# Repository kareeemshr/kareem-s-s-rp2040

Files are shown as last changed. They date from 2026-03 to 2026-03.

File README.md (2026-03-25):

# kareem-s-s-rp2040
(small note:there are decoupiling cap's clumped up together cus of space restrictions and no i cant really make the pcb 4 layers because im like 10 bucks away from being over budget)my very own custom devboard that i made...well i made it cus i thought itd be cool as hell and it is,im very proud of myself for making it but nonetheless:

you can use it like a normal raspberry pi pico as far as im aware.

i made it just to learn to how do this type of stuff because i really love the idea of me making my own stuff instead of buying it premade for me so like you could say my dream rn is to build my own custom keyboard but thats for when im actually good at this stuff and also when i get enough money.

**heres the schematic:**

**heres the pcb:**


**heres a render of the board(dont mind the drawings im inlove with sparta and the BOS)**:

|part|ammount|value|link|foot print|
|:----|:---:|:----:|----|----|
|Capacitor|11|0.1uF|https://jlcpcb.com/partdetail/1877-CL05B104KO5NNNC/C1525|0402|
|Capacitor|2|1uF|https://jlcpcb.com/partdetail/53938-CL05A105KA5NQNC/C52923|0402|
|capacitor|2|10uF|https://jlcpcb.com/partdetail/20411-CL10A106KP8NNNC/C19702|0603|
|capacitor|2|33pF|https://jlcpcb.com/partdetail/1914-0402CG330J500NT/C1562|0402|
|resistor|2|5.1K|https://jlcpcb.com/partdetail/26648-0402WGF5101TCE/C25905|0402|
|resistor|2|27|https://jlcpcb.com/partdetail/25843-0402WGF270JTCE/C25100|0402|
|resistor|2|1K|https://jlcpcb.com/partdetail/12256-0402WGF1001TCE/C11702|0402|
|resistor|1|10K|https://jlcpcb.com/partdetail/26487-0402WGF1002TCE/C25744|0402|
|push button|1||https://jlcpcb.com/partdetail/XUNPU-TS_1088AR02016/C720477|SW_Push_SPST_NO_Alps_SKRK|
|usb-c input|1||https://jlcpcb.com/partdetail/Korean_HropartsElec-TYPE_C_31_M12/C165948|USB_C_Receptacle_HRO_TYPE-C-31-M-12|
|MCU(rp 2040)|1||https://jlcpcb.com/partdetail/RaspberryPi-RP2040/C2040|QFN-56-1EP_7x7mm_P0.4mm_EP3.2x3.2mm|
|flash mem(W25Q16JVSS)|1|16MB|https://jlcpcb.com/partdetail/WinbondElec-W25Q16JVSSIQ/C131025|SOIC-8_5.3x5.3mm_P1.27mm|
|LOD(MCP1700x-330xxTT)|1|5.5V inpt 3.3V outp|https://jlcpcb.com/partdetail/MSKSEMI-MCP1700T_3302E_TT_MS/C20627188|SOT-23|
|crystal|1|12MHZ|https://jlcpcb.com/partdetail/NDK-NX3225GA_12MHZ_STD_CRG2/C481407|Crystal_SMD_3225-4Pin_3.2x2.5mm|

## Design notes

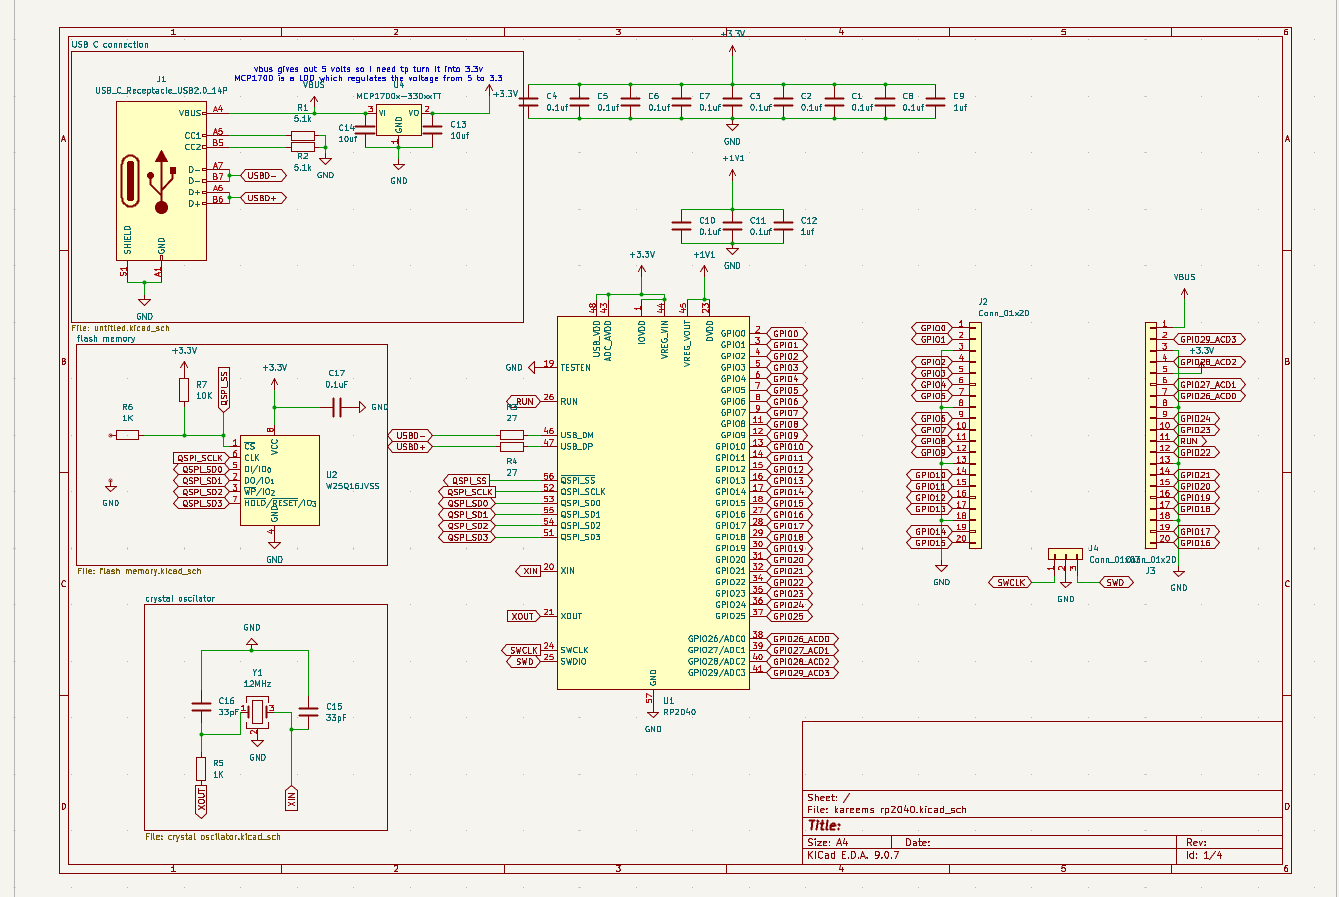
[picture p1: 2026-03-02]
photos/Screenshot 2026-03-03 020434.png

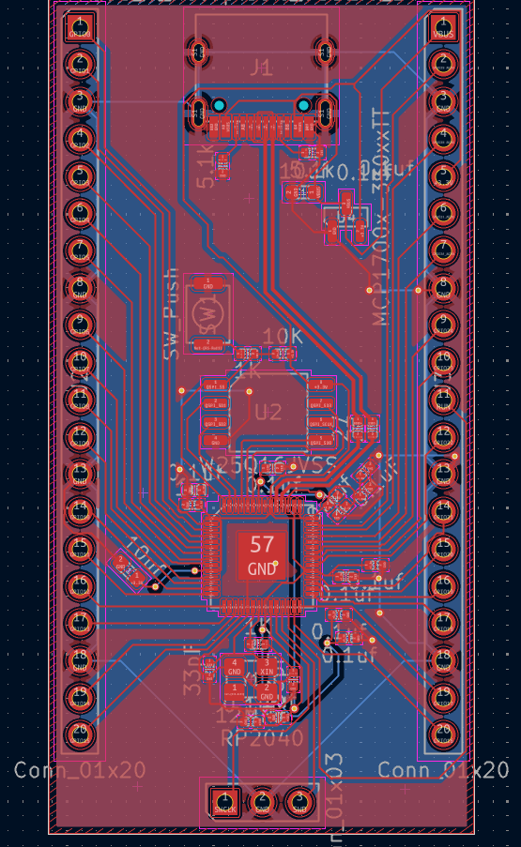
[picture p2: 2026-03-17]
photos/Screenshot 2026-03-17 214747.png

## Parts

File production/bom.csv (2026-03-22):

Designator | Footprint | Quantity | Value | LCSC Part #
C1, C10, C11, C17, C2, C3, C4, C5, C6, C7, C8 | 0402 | 11 | 0.1uf
C12, C9 | 0402 | 2 | 1uf
C13, C14 | 0603 | 2 | 10uf
C15, C16 | 0402 | 2 | 33pF
J1 | USB_C_Receptacle_HRO_TYPE-C-31-M-12 | 1 | USB_C_Receptacle_USB2.0_14P
J2, J3 | PinHeader_1x20_P2.54mm_Vertical | 2 | Conn_01x20
J4 | PinHeader_1x03_P2.54mm_Vertical | 1 | Conn_01x03
R1, R2 | 0402 | 2 | 5.1k
R3-1, R4+1 | 0402 | 2 | 27
R5, R6 | 0402 | 2 | 1K
R7 | 0402 | 1 | 10K
SW1 | SW_Push_SPST_NO_Alps_SKRK | 1 | SW_Push
U1 | QFN-56-1EP_7x7mm_P0.4mm_EP3.2x3.2mm | 1 | RP2040
U2 | SOIC-8_5.3x5.3mm_P1.27mm | 1 | W25Q16JVSS
U4 | SOT-23 | 1 | MCP1700x-330xxTT
Y1 | Crystal_SMD_3225-4Pin_3.2x2.5mm | 1 | 12MHz

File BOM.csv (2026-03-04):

part | value | ammount | link
C1 C10 C11 C17 C2 C3 C4 C5 C6 C7 C8 | 0.1uf | 11 | https://jlcpcb.com/partdetail/1877-CL05B104KO5NNNC/C1525
C12 C9 | 1uf | 2 | https://jlcpcb.com/partdetail/53938-CL05A105KA5NQNC/C52923
C13 C14 | 10uf | 2 | https://jlcpcb.com/partdetail/20411-CL10A106KP8NNNC/C19702
C15 C16 | 33pF | 2 | https://jlcpcb.com/partdetail/1914-0402CG330J500NT/C1562
USB_C_Receptacle_USB2.0_14P |  | 1 | https://jlcpcb.com/partdetail/Korean_HropartsElec-TYPE_C_31_M12/C165948
R1 R2 | 5.1K | 2 | https://jlcpcb.com/partdetail/26648-0402WGF5101TCE/C25905
R3 R4 | 27 | 2 | https://jlcpcb.com/partdetail/25843-0402WGF270JTCE/C25100
R5 R6 | 1K | 2 | https://jlcpcb.com/partdetail/12256-0402WGF1001TCE/C11702
R7 | 10K | 1 | https://jlcpcb.com/partdetail/26487-0402WGF1002TCE/C25744
SW1 |  | 1 | https://jlcpcb.com/partdetail/XUNPU-TS_1088AR02016/C720477
RP2040 |  | 1 | https://jlcpcb.com/partdetail/RaspberryPi-RP2040/C2040
W25Q16JVSS |  | 1 | https://jlcpcb.com/partdetail/WinbondElec-W25Q16JVSSIQ/C131025
MCP1700x-330xxTT |  | 1 | https://jlcpcb.com/partdetail/MSKSEMI-MCP1700T_3302E_TT_MS/C20627188
crystal | 12MHZ | 1 | https://jlcpcb.com/partdetail/NDK-NX3225GA_12MHZ_STD_CRG2/C481407

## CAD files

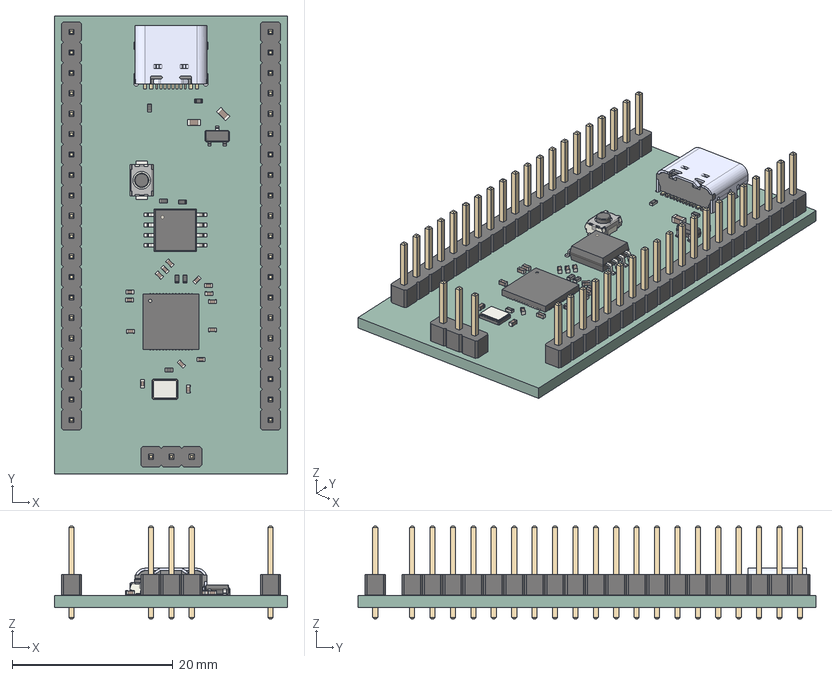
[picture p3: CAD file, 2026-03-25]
kareems rp2040.step
29.0 x 57.0 x 11.5 mm
R_0402_1005Metric x 7
C_0402_1005Metric x 15
SOIC-8_5.3x5.3mm_P1.27mm
QFN-56-1EP_7x7mm_P0.4mm_EP3.2x3.2mm
C_0603_1608Metric x 2
TYPE-C-31-M-12
Crystal_SMD_3225-4Pin_3.2x2.5mm
PinHeader_1x03_P2.54mm_Vertical
PinHeader_1x20_P2.54mm_Vertical x 2
SOT-23
SW_Push_SPST_NO_Alps_SKRK
kareems rp2040_PCB

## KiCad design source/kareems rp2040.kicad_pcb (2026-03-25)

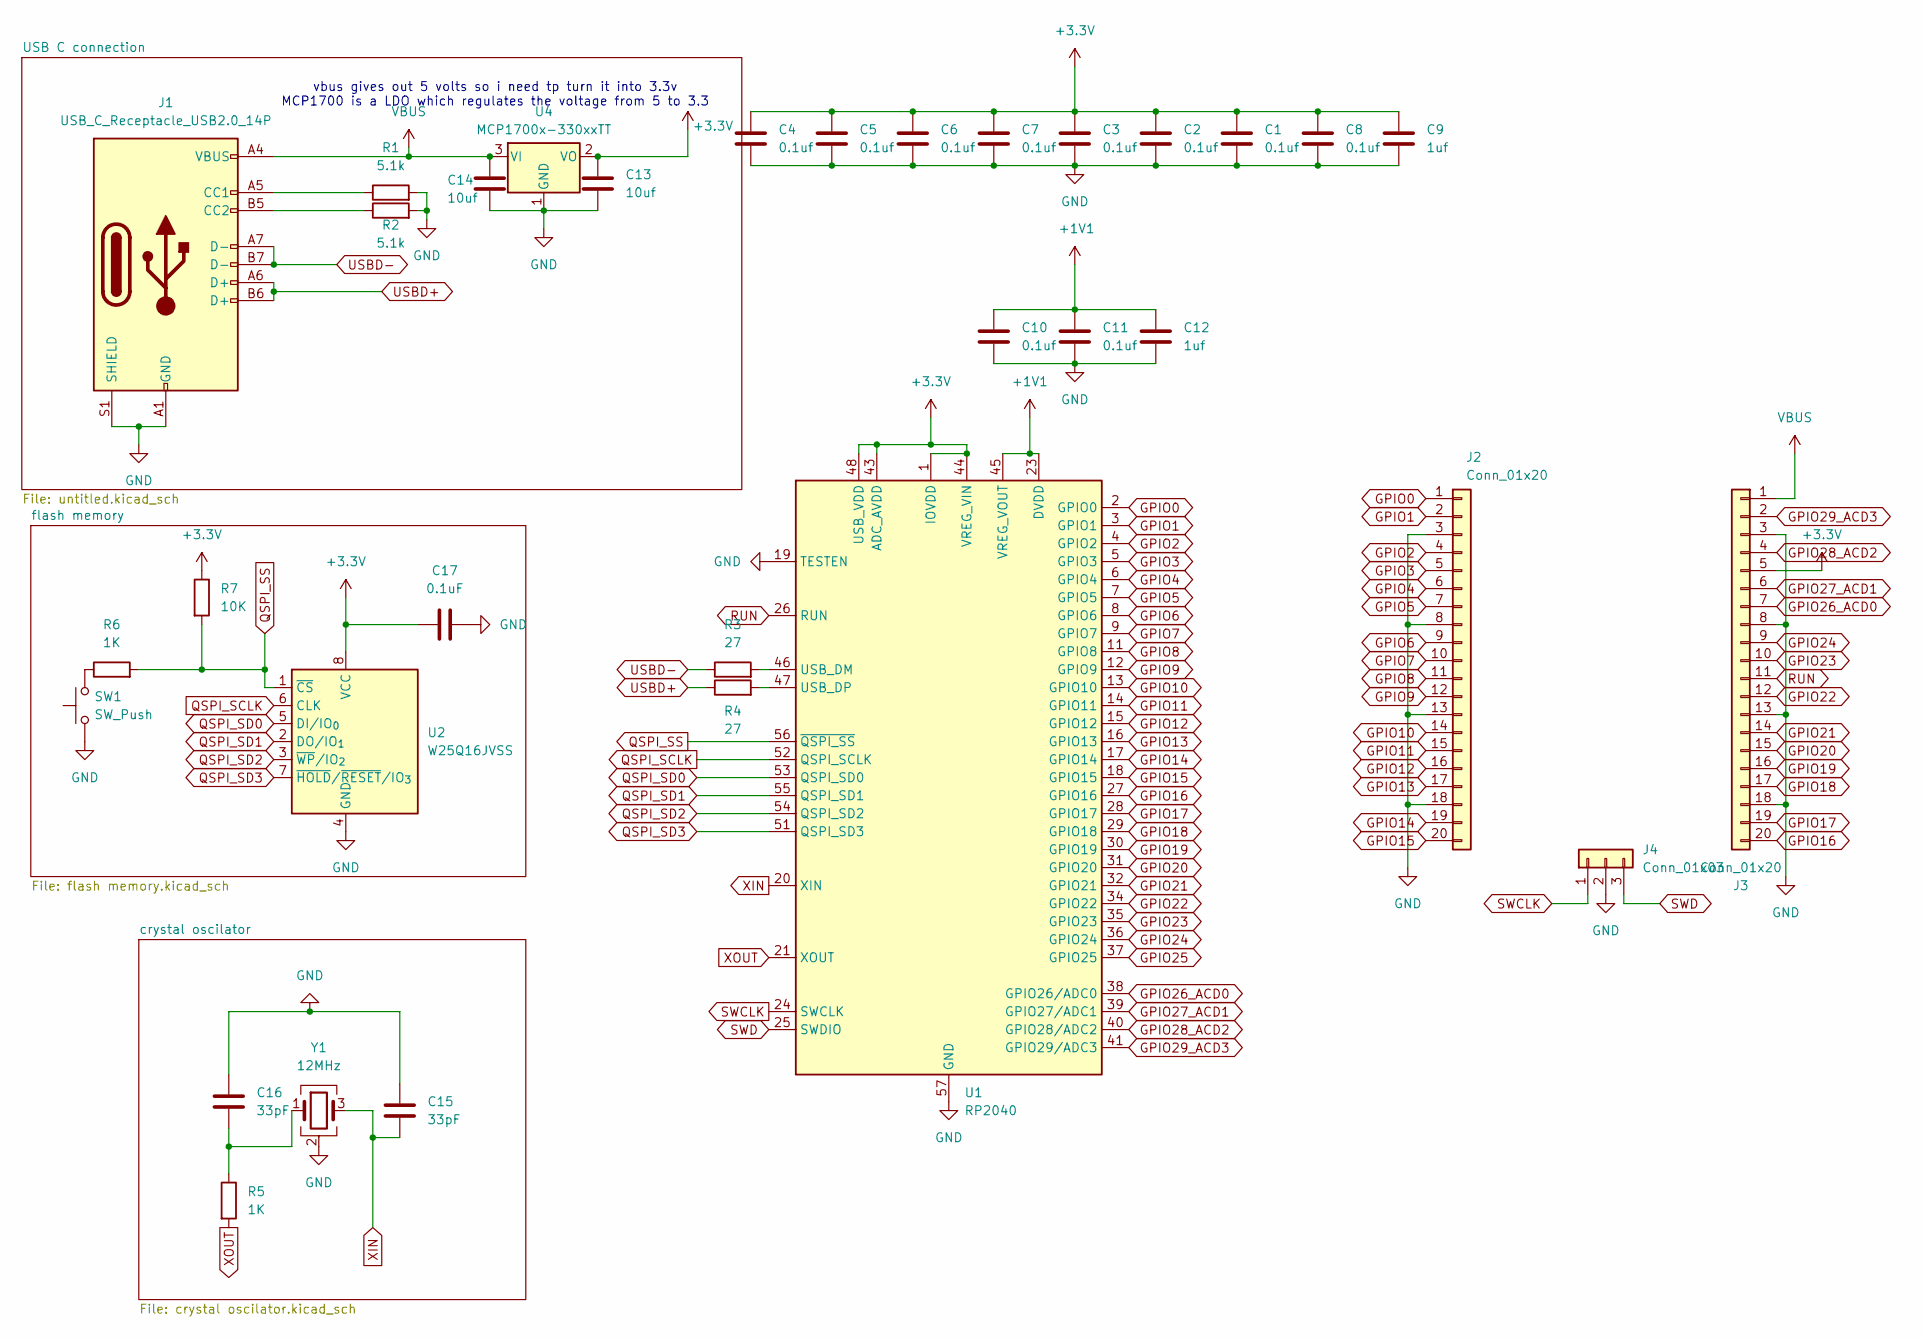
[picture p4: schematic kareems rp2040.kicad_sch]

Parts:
C1, C2, C3, C4, C5, C6, C7, C8, C10, C11: 0.1uf; C_0402_1005Metric
C9, C12: 1uf; C_0402_1005Metric
C13, C14: 10uf; C_0603_1608Metric
C15, C16: 33pF; C_0402_1005Metric
C17: 0.1uF; C_0402_1005Metric
J1: USB_C_Receptacle_USB2.0_14P; USB_C_Receptacle_HRO_TYPE-C-31-M-12
J2, J3: Conn_01x20; PinHeader_1x20_P2.54mm_Vertical
J4: Conn_01x03; PinHeader_1x03_P2.54mm_Vertical
R1, R2: 5.1k; R_0402_1005Metric
R3, R4: 27; R_0402_1005Metric
R5, R6: 1K; R_0402_1005Metric
R7: 10K; R_0402_1005Metric
SW1: SW_Push; SW_Push_SPST_NO_Alps_SKRK
U1: RP2040; QFN-56-1EP_7x7mm_P0.4mm_EP3.2x3.2mm
U2: W25Q16JVSS; SOIC-8_5.3x5.3mm_P1.27mm
U4: MCP1700x-330xxTT; SOT-23
Y1: 12MHz; Crystal_SMD_3225-4Pin_3.2x2.5mm

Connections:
+1V1: C10.1, C11.1, C12.1, U1.23 (DVDD), U1.45 (VREG_VOUT), U1.50 (DVDD)
+3.3V: C1.1, C2.1, C3.1, C4.1, C5.1, C6.1, C7.1, C8.1, C9.1, C13.1, C17.1, J3.5, R7.1, U1.1 (IOVDD), U1.10 (IOVDD), U1.22 (IOVDD), U1.33 (IOVDD), U1.42 (IOVDD), U1.43 (ADC_AVDD), U1.44 (VREG_VIN), U1.48 (USB_VDD), U1.49 (IOVDD), U2.8 (VCC), U4.2 (VO)
GND: C1.2, C2.2, C3.2, C4.2, C5.2, C6.2, C7.2, C8.2, C9.2, C10.2, C11.2, C12.2, C13.2, C14.2, C15.2, C16.2, C17.2, J1.A1 (GND), J1.A12 (GND), J1.B1 (GND), J1.B12 (GND), J1.S1 (SHIELD), J2.3, J2.8, J2.13, J2.18, J3.3, J3.8, J3.13, J3.18, J4.2, R1.2, R2.2, SW1.1, U1.19 (TESTEN), U1.57 (GND), U2.4 (GND), U4.1 (GND), Y1.2 (G), Y1.4 (G)
GPIO0: J2.1, U1.2 (GPIO0)
GPIO1: J2.2, U1.3 (GPIO1)
GPIO2: J2.4, U1.4 (GPIO2)
GPIO3: J2.5, U1.5 (GPIO3)
GPIO4: J2.6, U1.6 (GPIO4)
GPIO5: J2.7, U1.7 (GPIO5)
GPIO6: J2.9, U1.8 (GPIO6)
GPIO7: J2.10, U1.9 (GPIO7)
GPIO8: J2.11, U1.11 (GPIO8)
GPIO9: J2.12, U1.12 (GPIO9)
GPIO10: J2.14, U1.13 (GPIO10)
GPIO11: J2.15, U1.14 (GPIO11)
GPIO12: J2.16, U1.15 (GPIO12)
GPIO13: J2.17, U1.16 (GPIO13)
GPIO14: J2.19, U1.17 (GPIO14)
GPIO15: J2.20, U1.18 (GPIO15)
GPIO16: J3.20, U1.27 (GPIO16)
GPIO17: J3.19, U1.28 (GPIO17)
GPIO18: J3.17, U1.29 (GPIO18)
GPIO19: J3.16, U1.30 (GPIO19)
GPIO20: J3.15, U1.31 (GPIO20)
GPIO21: J3.14, U1.32 (GPIO21)
GPIO22: J3.12, U1.34 (GPIO22)
GPIO23: J3.10, U1.35 (GPIO23)
GPIO24: J3.9, U1.36 (GPIO24)
GPIO25: U1.37 (GPIO25)
GPIO26_ACD0: J3.7, U1.38 (GPIO26/ADC0)
GPIO27_ACD1: J3.6, U1.39 (GPIO27/ADC1)
GPIO28_ACD2: J3.4, U1.40 (GPIO28/ADC2)
GPIO29_ACD3: J3.2, U1.41 (GPIO29/ADC3)
unnamed: C16.1, R5.1, Y1.1
unnamed: J1.A5 (CC1), R1.1
unnamed: J1.B5 (CC2), R2.1
unnamed: R6.1, SW1.2
unnamed 37: R3.2, U1.46 (USB_DM); also elsewhere on the board
unnamed 38: R4.2, U1.47 (USB_DP); also elsewhere on the board
QSPI_SCLK: U1.52 (QSPI_SCLK), U2.6 (CLK)
QSPI_SD0: U1.53 (QSPI_SD0), U2.5 (DI/IO_{0})
QSPI_SD1: U1.55 (QSPI_SD1), U2.2 (DO/IO_{1})
QSPI_SD2: U1.54 (QSPI_SD2), U2.3 (~WP/IO_{2})
QSPI_SD3: U1.51 (QSPI_SD3), U2.7 (~HOLD/~RESET/IO_{3})
QSPI_SS: R6.2, R7.2, U1.56 (~QSPI_SS), U2.1 (~CS)
RUN: J3.11, U1.26 (RUN)
SWCLK: J4.1, U1.24 (SWCLK)
SWD: J4.3, U1.25 (SWDIO)
USBD+: J1.A6 (D+), J1.B6 (D+), R4.1; also elsewhere on the board
USBD-: J1.A7 (D-), J1.B7 (D-), R3.1; also elsewhere on the board
VBUS: C14.1, J1.A4 (VBUS), J1.A9 (VBUS), J1.B4 (VBUS), J1.B9 (VBUS), J3.1, U4.3 (VI)
XIN: C15.1, U1.20 (XIN), Y1.3
XOUT: R5.2, U1.21 (XOUT)

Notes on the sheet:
vbus gives out 5 volts so i need tp turn it into 3.3v MCP1700 is a LDO which regulates the voltage from 5 to 3.3

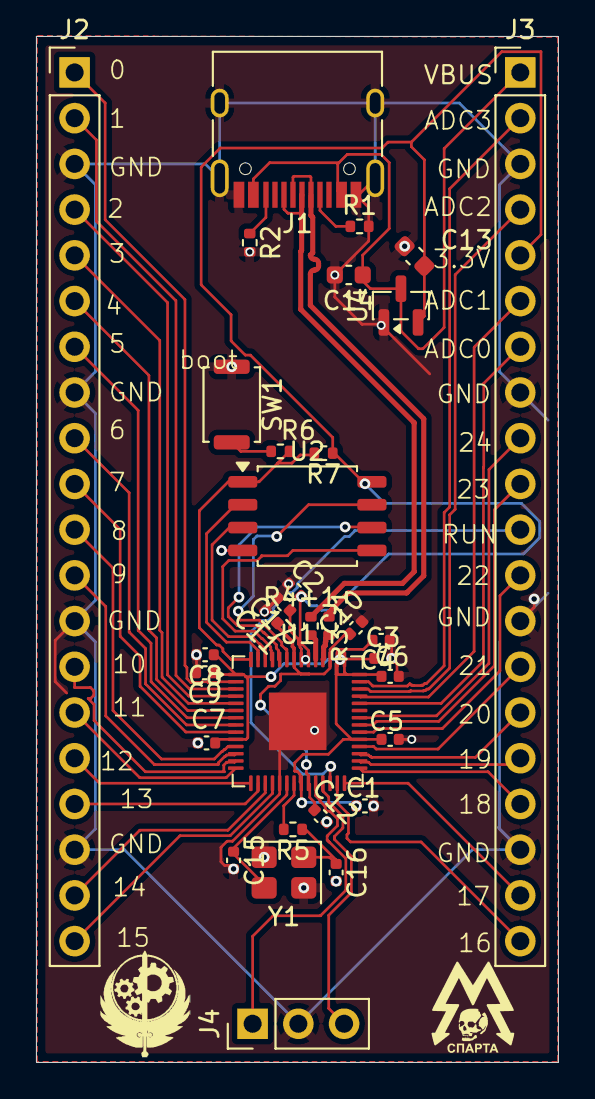
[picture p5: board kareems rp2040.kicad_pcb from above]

Board: 2 copper layers, 29.0 x 57.0 mm, 33 parts (0 on the bottom side), 52 nets.

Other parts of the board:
R3-1, R4+1: 27; R_0402_1005Metric

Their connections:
unnamed 37: R3-1.2; also elsewhere on the board
unnamed 38: R4+1.2; also elsewhere on the board
USBD+: R4+1.1; also elsewhere on the board
USBD-: R3-1.1; also elsewhere on the board

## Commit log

2026-03-02 added project files
    [bom-JLCPCB Assembly Order.xls, crystal oscilator.kicad_sch, designators.csv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]
2026-03-03 fixed the location of prodcution file
    [bom-JLCPCB Assembly Order.xls, designators.csv, positions.csv]
2026-03-03 Enhance README formatting and add parts list
    Formatted schematic, PCB, and render sections for clarity. Added a detailed parts list with links and specifications.
2026-03-04 fixed the name of the source file
    [bom-JLCPCB Assembly Order.xls, crystal oscilator.kicad_sch, flash memory.kicad_sch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]
2026-03-05 Update schematic and PCB images in README
2026-03-17 Update README with new PCB image and board render
    Added additional PCB image and updated board render.
2026-03-25 Update PCB and render images in README
